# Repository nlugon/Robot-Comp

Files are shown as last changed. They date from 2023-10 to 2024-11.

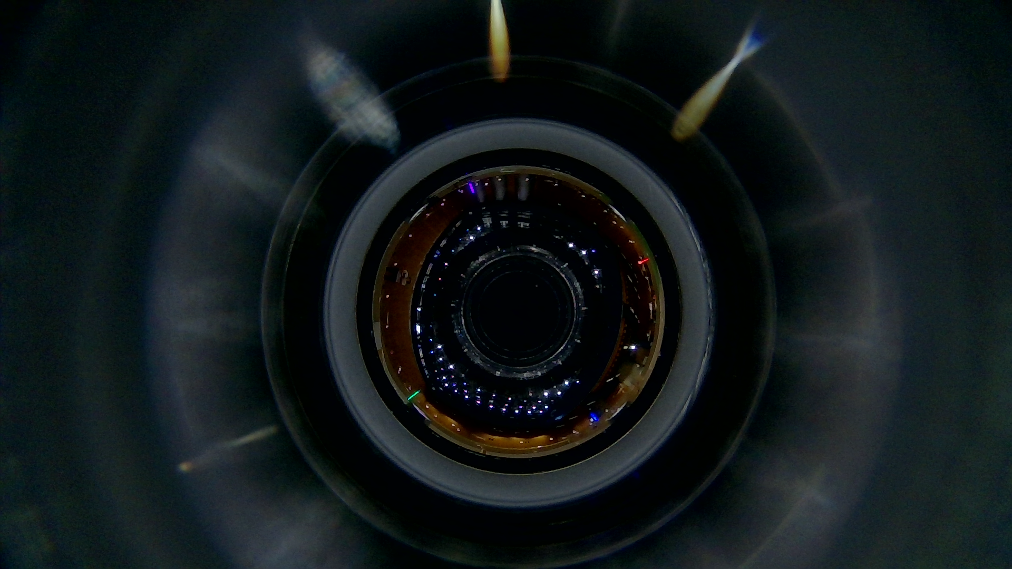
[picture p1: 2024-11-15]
Code/Utils/TestImages/image.png

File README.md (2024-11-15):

# Interdisciplinary Robot Competition

leroboteny

Competition website [here](https://robot-competition.epfl.ch) 

Video of the robot [here (youtube)](https://www.youtube.com/watch?v=vqCzc3zlJ8U)

Robot Competition Report [here](https://drive.google.com/file/d/1sISDkwHlUgYIt9PJVt_OxYXLAwWDXRC6/view)

## Authors
- [Noah Lugon](https://github.com/nlugon)
- [Clarence Linden](https://gitlab.epfl.ch/linden)
- [Adrien Chevallier](https://gitlab.epfl.ch/achevall)

## Electrical Components
- Arduino -> low level processing unit
- Raspberry Pi -> high level processing unit
- Maxon motors -> high precision motors for differential drive locomotion 
- Polulu motors -> motors for turning front brushes
- Servo motor -> for duplo brick unloading
- Servo driver -> Adafruit 16-Channel 12-bit PWM/Servo Driver (controlled by Arduino via I2C)
- Ultrasonic distance senors -> for distance measuring
- LEDs -> WS2812B Addressable RGB LED Strip with 32 LEDs used for esthetic as well as debugging purposes
    Center LEDs (14 to 17) used to indicate battery level
    Left and right LEDs (0-9 and 22-31) used to indicate if obstacle detected on left or right side (display in pink)
        Left and right LEDs also used to indicate other modes (turquoise for unloading, yellow for pressing button, 
            red for maneuver due to too high Maxon motor current, blue for maneuver if get stuck too long in a corner)

## Features
- Maxon motor speed control
- Maxon motor sensor data reading 
    Speed data for odometry -> if robot keeps detecting an obstacle in the same position, will make maneuver (turn randomly left or right by approx 180 deg)
    Current sensing -> if duplo ramp gets stuck under carpet, robot senses unusually high torque and makes backwards maneuver, followed by random left or right maneuver
- Polulu motor speed control (tuned constant speed here)
- Polulu motor encoder reading (if either of the two motors has low speed or gets stuck -> direction reversed for both motors to push duplo brick out)
- Servo control for unloading
- Simple and very robust obstacle avoidance by reversing direction of motor when an obstacle on the opposite side of the robot is detected
- Obstacle avoidance disabled during maneuvers, as well as when Arduino is commanded to run straight to the button (current sensing then used to determine when button is pressed)
  Extra feature of button pressing : when button pressed, robot always turns left (use_random_direction boolean set to false, set back to true once Raspberry Pi sends new motor command "m...") 

- Serial communication with Raspberry pi
Motor commands : "m+99-50" (first three characters after the 'm' is for the left motor, then the next three for the right)
    This custom protocal using a '+' or '-' character enables to choose between positive or negative motor speeds
Unloading command : "u"
Full arduino autonomous mode : "a" (basically resets default speed to +99 on left and right motors)
Move forward to push button : "b"
Emergency STOP command : "s"
Raspberry pi requests data : "d"
    Upon request, data formats received from arduino to raspberry pi :
        "dxxx xxx xxx xxx xxx xxx " with "xxx" representing distance measured by ultrasonic sensor in cm 
    As soon as low battery detected : "b" sent continuously, indicating low battery voltage -> robot should return to collecting point and stop brushes from turning to save battery      
Polulu motor command : "D1" to turn off, "D0" to turn on (default) (D for Debug)
    Note : if D0 sent but the polulus are not connected to the power source, there will be very high delayes due to the pulseIn() function awaiting motor encoder data (timeout set to 250ms)

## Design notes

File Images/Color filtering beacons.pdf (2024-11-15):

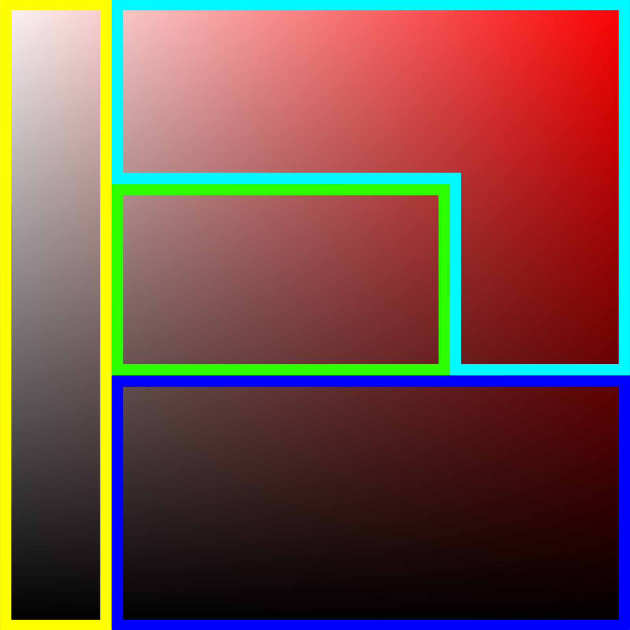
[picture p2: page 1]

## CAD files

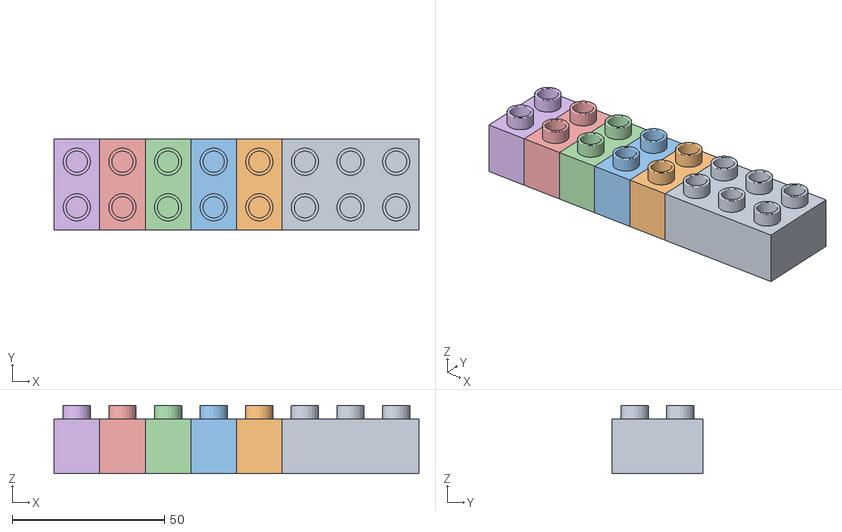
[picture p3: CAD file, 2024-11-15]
blender/Models Data/Duplo Parametrique 2x8.obj
120.0 x 30.0 x 22.5

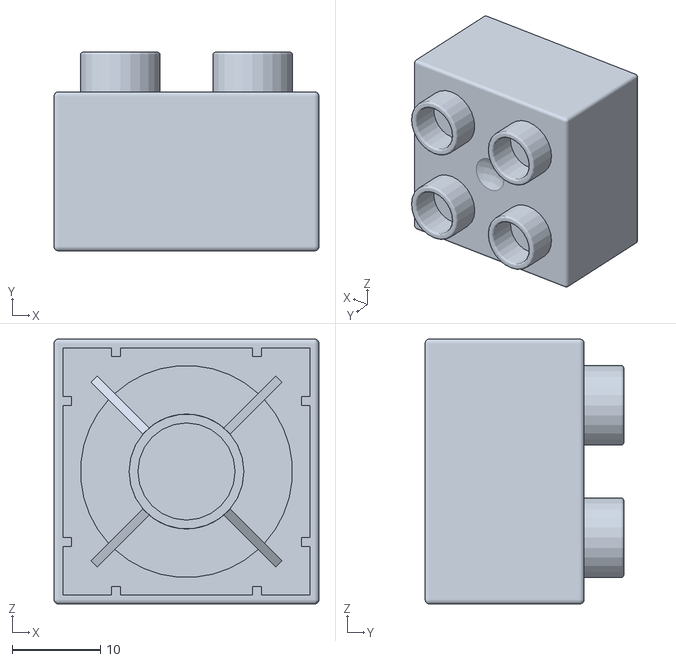
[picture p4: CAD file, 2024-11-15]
blender/Models Data/Duplo Parametrique 2x2.obj
30.0 x 22.5 x 30.0

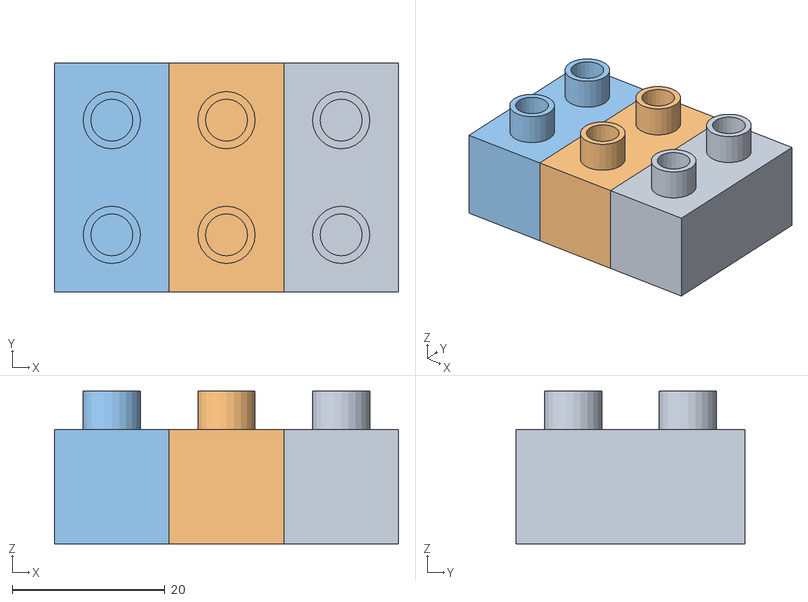
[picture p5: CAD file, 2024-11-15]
blender/Models Data/new/Duplo Parametrique 2x3.obj
45.0 x 30.0 x 20.0

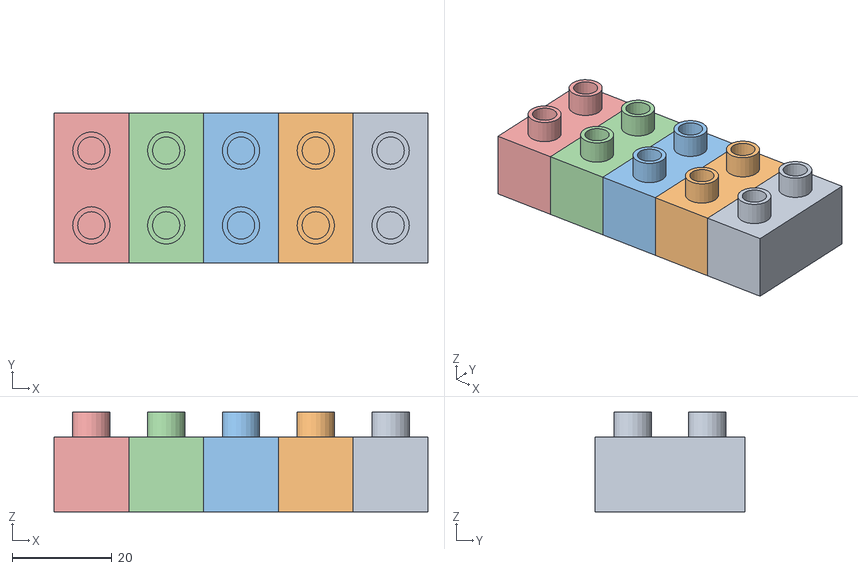
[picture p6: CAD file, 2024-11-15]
blender/Models Data/Duplo Parametrique 2x5.obj
75.0 x 30.0 x 20.0

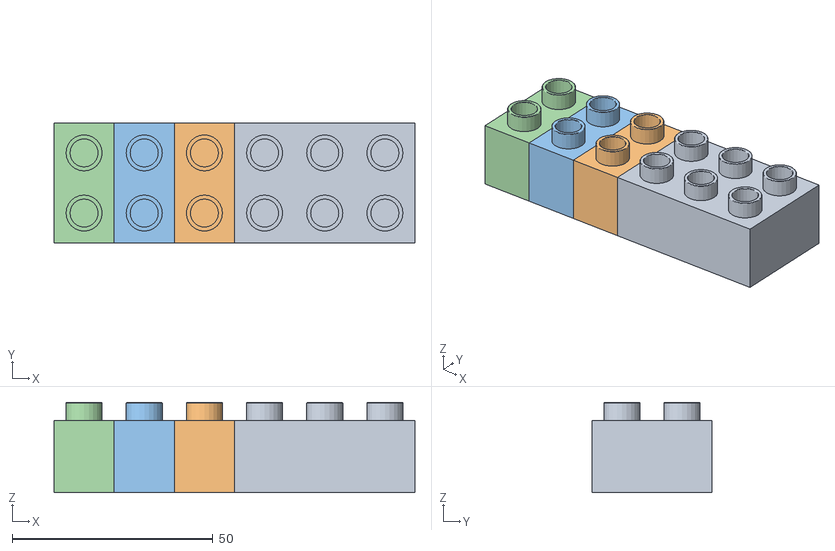
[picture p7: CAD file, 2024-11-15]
blender/Models Data/Duplo Parametrique 2x6.obj
90.0 x 30.0 x 22.5

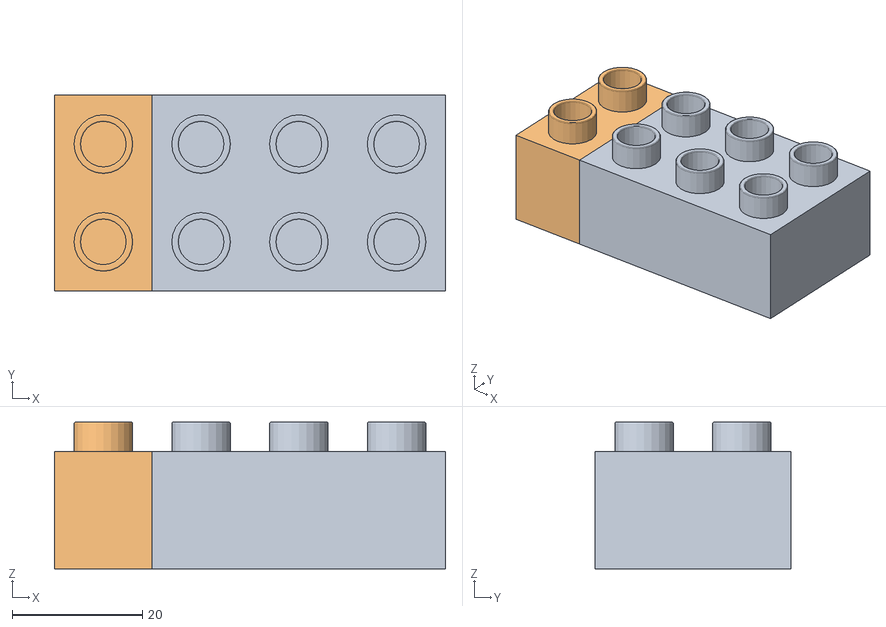
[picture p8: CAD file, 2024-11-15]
blender/Models Data/Duplo Parametrique 2x4.obj
60.0 x 30.0 x 22.5

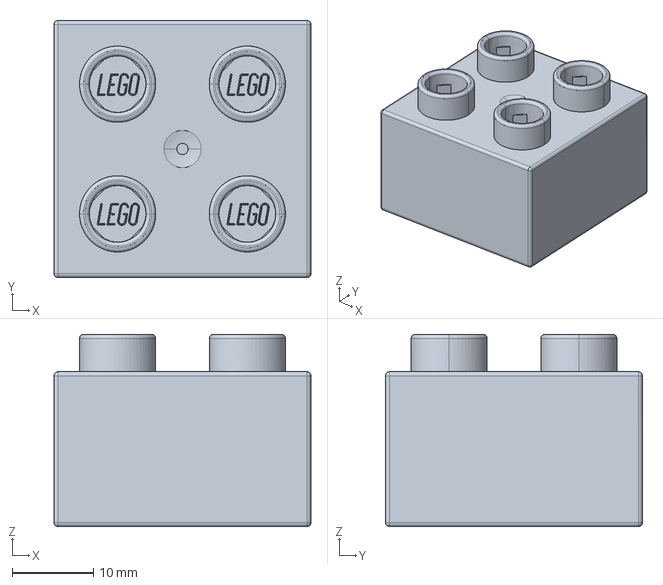
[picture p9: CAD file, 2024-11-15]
blender/Models Data/new/LEGO_DUPLO_BRICK_2X2.igs
31.7 x 31.7 x 23.7 mm

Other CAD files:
blender/Models Data/new/Duplo Parametrique 2x8.obj
blender/Models Data/new/Duplo Parametrique 2x5.obj
blender/Models Data/new/Duplo Parametrique 2x6.obj
blender/Models Data/Duplo Parametrique 2x3.obj
blender/Models Data/new/Duplo Parametrique 2x2.obj
blender/Models Data/new/Duplo Parametrique 2x4.obj
blender/Models Data/new/LEGO_DUPLO_BRICK_2X2 v1.stl

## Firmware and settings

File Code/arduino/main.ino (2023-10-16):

/* ARDUINO CODE 
  by Noah Lugon, last updated April 14 2023


  Main Components :
    - Arduino -> low level processing unit
    - Raspberry Pi -> high level processing unit
    - Maxon motors -> high precision motors for differential drive locomotion 
    - Polulu motors -> motors for turning front brushes
    - Servo motor -> for duplo brick unloading
    - Servo driver -> Adafruit 16-Channel 12-bit PWM/Servo Driver (controlled by Arduino via I2C)
    - Ultrasonic distance senors -> for distance measuring
    - LEDs -> WS2812B Addressable RGB LED Strip with 32 LEDs used for esthetic as well as debugging purposes
        Center LEDs (14 to 17) used to indicate battery level
        Left and right LEDs (0-9 and 22-31) used to indicate if obstacle detected on left or right side (display in pink)
            Left and right LEDs also used to indicate other modes (turquoise for unloading, yellow for pressing button, 
                red for maneuver due to too high Maxon motor current, blue for maneuver if get stuck too long in a corner)

  Features :
  - Maxon motor speed control
  - Maxon motor sensor data reading 
        Speed data for odometry -> if robot keeps detecting an obstacle in the same position, will make maneuver (turn randomly left or right by approx 180 deg)
        Current sensing -> if duplo ramp gets stuck under carpet, robot senses unusually high torque and makes backwards maneuver, followed by random left or right maneuver
  - Polulu motor speed control (tuned constant speed here)
  - Polulu motor encoder reading (if either of the two motors has low speed or gets stuck -> direction reversed for both motors to push duplo brick out)
  - Servo control for unloading
  - Simple and very robust obstacle avoidance by reversing direction of motor when an obstacle on the opposite side of the robot is detected
  - Obstacle avoidance disabled during maneuvers, as well as when Arduino is commanded to run straight to the button (current sensing then used to determine when button is pressed)
      Extra feature of button pressing : when button pressed, robot always turns left (use_random_direction boolean set to false, set back to true once Raspberry Pi sends new motor command "m...") 


  - Serial communication with Raspberry pi
    Motor commands : "m+99-50" (first three characters after the 'm' is for the left motor, then the next three for the right)
        This custom protocal using a '+' or '-' character enables to choose between positive or negative motor speeds
    Unloading command : "u"
    Full arduino autonomous mode : "a" (basically resets default speed to +99 on left and right motors)
    Move forward to push button : "b"
    Emergency STOP command : "s"
    Raspberry pi requests data : "d"
        Upon request, data formats received from arduino to raspberry pi :
            "dxxx xxx xxx xxx xxx xxx " with "xxx" representing distance measured by ultrasonic sensor in cm 
        As soon as low battery detected : "b" sent continuously, indicating low battery voltage -> robot should return to collecting point and stop brushes from turning to save battery      
    Polulu motor command : "D1" to turn off, "D0" to turn on (default) (D for Debug)
        Note : if D0 sent but the polulus are not connected to the power source, there will be very high delayes due to the pulseIn() function awaiting motor encoder data (timeout set to 250ms)


  WARNING ultrasonic sensor sometimes ouptut a value of 0 even when no obstacle is detected
    (solution : ignore 0 values, works very well in practice)

  WARNING When running the full code, the data sent from the Arduino to the Rasbperry Pi caused unexpected crashes of the main program on the Raspbery Pi.
      As we were unable to resolve this issue, no Serial data is sent to the Rasbperry Pi from the Arduino (no Serial.print())




  MAXON LEFT MOTOR CONNECTED TO MAXON CONTROLLER # 4
  Polulu left motor connected to M1 port of the motor driver

*/ 



#include <Servo.h>
#include <FastLED.h>

#include <Wire.h>
#include <Adafruit_PWMServoDriver.h>
Adafruit_PWMServoDriver pwm = Adafruit_PWMServoDriver();



#define SERVOMIN  200 // This is the 'minimum' pulse length count (out of 4096)
#define SERVOMAX  500 // This is the 'maximum' pulse length count (out of 4096)
#define SERVO_FREQ 60 // Analog servos run at ~50 Hz updates

#define LED_PIN     7
#define NUM_LEDS    32

#define ULTRASONIC_INTERVAL 40 // Milliseconds between sensor pings (29ms is about the min to avoid cross-sensor echo).
#define ULTRASONIC_NUM 5 // Number of sensors




bool DEBUG = 0;
bool use_random_direction = 1;
int randomNumber;
bool use_adafruit_driver = 1;


// FSM state
int fsmState = 0; // when state = 0, simple forward movement and obstacle avoidance
int turnTime = 1500;

// Polulu motor state and default speed
bool polulusOn = 1;
int poluluSpeed = 70; 

// variables used to detect changes of state between obstacle being detected / no longer being detected
bool obstacle = 0;
bool obstacleLeft = 0;
bool obstacleRight = 0;
bool prevObstacle = 0;
bool prevObstacleLeft = 0;
bool prevObstacleRight = 0;
bool NewObstacleState = 0; // if equals 1, indicates a change of state from (no obstacles detected) to (obstacle detected).




// LEDs
CRGB leds[NUM_LEDS];
// table of LED values, we found this is faster than using 
int ledStates[NUM_LEDS] = {0,0,0,0,0,0,0,0,0,0,0,0,0,0,0,0,0,0,0,0,0,0,0,0,0,0,0,0,0,0,0,0};
int prevLedStates[NUM_LEDS] = {0,0,0,0,0,0,0,0,0,0,0,0,0,0,0,0,0,0,0,0,0,0,0,0,0,0,0,0,0,0,0,0};


unsigned long currentTime = 0;

unsigned long ultrasonicTimer[ULTRASONIC_NUM]; // Holds the times when the next ping should happen for each sensor.
unsigned int cm[ULTRASONIC_NUM] = {100,100,100,100,100};         // Where the measured ultrasonic distances are stored.
bool obstacleState[ULTRASONIC_NUM] = {0,0,0,0,0};
//uint8_t currentUltrasonicSensor = 0;          // Keeps track of which sensor is active.
//unsigned int  ultrasonicSensors[ULTRASONIC_NUM];
// ULTRASONIC PINS
// const int ultrasonicTrigPins[ULTRASONIC_NUM] = {30,32,34,36,38,40};
// const int ultrasonicEchoPins[ULTRASONIC_NUM] = {31,33,35,37,39,41};
const int ultrasonicTrigPins[ULTRASONIC_NUM] = {42,32,34,36,38};
const int ultrasonicEchoPins[ULTRASONIC_NUM] = {43,33,35,37,39};



// SERVOMOTOR

// using adafruit driver
uint8_t servonum = 0;

// using arduino analogWrite pin
const int bigAssServoPin = 3;
int pos = 30;
Servo bigAssServo;





// MAXON CONTROLLER PINS
const int leftMotorEnablePin = 22;
const int leftMotorDirectionPin = 23;
const int leftMotorPwmPin = 10;

const int rightMotorEnablePin = 24;
const int rightMotorDirectionPin = 25;
const int rightMotorPwmPin = 11;

// DC MOTOR DRIVER PINS
const int MotorADirectionPin = 52;
const int MotorAPwmPin = 8;
const int MotorAEncoderPin = 50;

const int MotorBDirectionPin = 53;
const int MotorBPwmPin = 9;
const int MotorBEncoderPin = 51;


unsigned long startMillis;  // some global variables available anywhere in the program
unsigned long currentMillis;
const unsigned long poluluPeriod = 1000;  // after polulu motors detected to be stuck, turn brushes for 1s in outwards direction to spit out duplos 
const unsigned long poluluPeriodUnstuck = 200; // after polulu motos unstuck, give 200ms time for brushes to turn back inwards


unsigned long fsmStartMillis;
unsigned long fsmCurrentMillis;
const unsigned long fsmPeriod = 1000;

unsigned long obstacleCounter = 0;

unsigned long serialStartMillis;
unsigned long serialCurrentMillis;

unsigned long odometryStartMillis;
unsigned long odometryCurrentMillis;

// Maxon motor speed and drawn current data
int speedLeft = 0;
int currentLeft = 0;
int speedRight = 0;
int currentRight = 0;

// Odometry
long positionLeft;
long positionRight;
long positionForward;
long prevPositionForward;
long positionAngular;
bool not_moving_forward;

// Battery Monitoring
int batteryLevel = 0;

// Polulu motor encoder info
int ontimeA,offtimeA,dutyA;
float freqA, periodA;
int ontimeB,offtimeB,dutyB;
float freqB, periodB;
bool motorAstuck = 0;
bool motorBstuck = 0;

// Variables for ultrasonic sensors
long duration, distance, sonicSensor1;

// Communication with Raspberry Pi : 
String msg = "";

int left_speed = 99; // WARNING value between -99 and 99
int right_speed = 99; // WARNING value between -99 and 99



// FUNCTIONS
void SonarSensor();
void updateMotorCommands();
void getData();
void sendData();
void readSerialPort();
void sensorAvoidance();
void updatePoluluCommands();
void unloading();
void moveServos();
void adafruitCommand(int startPulse, int endPulse);
void analogWriteCommand(int startPos, int endPos);
void checkBatteryLevel();

void checkMotors();
void fsm();
void newFSMstate(int stateNumber = 0);

void updateLEDs();
void updateSideLEDs(int color);









/********************* SETUP *********************/

void setup() {
  // put your setup code here, to run once:
  Serial.begin(115200); // Initialize serial communication with computer

  // while (!Serial) {
  //   delay(10); // wait for serial port to connect. Needed for native USB port only
  // }


  // LEDs Initialization
  FastLED.addLeds<WS2812, LED_PIN, GRB>(leds, NUM_LEDS);
  // FastLED.setBrightness(10);
  for (uint8_t i = 0; i <= 31; i++) {
    leds[i] = CRGB (0, 0, 10); // blue
    FastLED.show();
    delay(40);
  }
  for (uint8_t i = 0; i <= 31; i++) {
    leds[i] = CRGB (0, 0, 0); // blue
    FastLED.show();
    delay(40);
  }

  checkBatteryLevel();
  updateLEDs();


  // SERVO CHECK : tilt duplo container up once upon startup
  if (use_adafruit_driver) {
      pwm.begin();
      pwm.setOscillatorFrequency(27000000);
      pwm.setPWMFreq(SERVO_FREQ);  // Analog servos run at ~50 Hz updates
      pwm.setPWM(servonum, 0, SERVOMIN);
      delay(1000);
      pwm.setPWM(servonum, 0, SERVOMAX);
      delay(1000);
      pwm.setPWM(servonum, 0, SERVOMIN);
      delay(1000);
      pwm.setPWM(0, 0, 0);  // turn off PWM signal to avoid servo humming
  }
  else {
    // SET PINS FOR SERVOMOTOR
    bigAssServo.attach(bigAssServoPin);
    bigAssServo.write(30);
    delay(1000);
    bigAssServo.write(130);
    delay(1000);
    bigAssServo.write(30);
    delay(1000);
  }


  // Odometry
  positionLeft = 0;
  positionRight = 0;
  positionForward = 0;
  prevPositionForward = positionForward;
  positionAngular = 0; 



  // SET PINMODE OF ULTRASONIC SENSORS
  for (uint8_t i = 0; i < ULTRASONIC_NUM; i++) { 
      pinMode(ultrasonicTrigPins[i], OUTPUT);
      pinMode(ultrasonicEchoPins[i], INPUT);
  }  

  // SET TIME WHEN EACH SENSOR SENDS PULSE (one after the other to avoid interference between sensors)
  ultrasonicTimer[0] = millis() + 1000; // First pulse starts at 1000ms
  for (uint8_t i = 1; i < ULTRASONIC_NUM; i++) { // Set the starting time for each sensor.
      ultrasonicTimer[i] = ultrasonicTimer[i - 1] + ULTRASONIC_INTERVAL;
  }

  
  // SET UP MAXON MOTOR CONTROLLER ********************
  pinMode(leftMotorEnablePin, OUTPUT);
  pinMode(leftMotorDirectionPin, OUTPUT);
  pinMode(leftMotorPwmPin, OUTPUT);
  pinMode(rightMotorEnablePin, OUTPUT);
  pinMode(rightMotorDirectionPin, OUTPUT);
  pinMode(rightMotorPwmPin, OUTPUT);

  digitalWrite(leftMotorEnablePin, HIGH); 
  digitalWrite(leftMotorDirectionPin, HIGH); 
  digitalWrite(rightMotorEnablePin, HIGH);
  digitalWrite(rightMotorDirectionPin, HIGH);

  analogWrite(leftMotorPwmPin,26); // pwm duty cycle set initially to 10% (corresponds to 0 speed)
  analogWrite(rightMotorPwmPin,26); // pwm duty cycle set initially to 10% (corresponds to 0 speed)

  // SET UP DC MOTOR DRIVER *********************
  pinMode(MotorADirectionPin, OUTPUT);
  pinMode(MotorAPwmPin, OUTPUT);
  pinMode(MotorAEncoderPin, INPUT);
  pinMode(MotorBDirectionPin, OUTPUT);
  pinMode(MotorBPwmPin, OUTPUT);
  pinMode(MotorBEncoderPin, INPUT);

  digitalWrite(MotorADirectionPin, LOW);
  digitalWrite(MotorBDirectionPin, HIGH);
  analogWrite(MotorAPwmPin, 80);
  analogWrite(MotorBPwmPin, 80);



  // Variables for time measurement purposes (to not slow down everything with delay() )
  startMillis = millis(); // for polulu motors
  currentMillis = startMillis;

  fsmStartMillis = millis(); // for FSM
  fsmCurrentMillis = millis();
 
  serialStartMillis = millis(); // for serial communication (if Raspberry Pi no longer communicating to Arduino -> arduino sets speeds back to default)
  serialCurrentMillis = serialStartMillis;

  odometryStartMillis = millis(); // for odometry (get position from motor speeds)
  odometryCurrentMillis = odometryStartMillis;

  turnTime = 1500;
  // Say hello for sake of politeness
  // Serial.println("Hello from Arduinoooo");
  delay(1000); // wait 1 second


}



/********************* LOOP *********************/ 

void loop() {


  getData(); // get data from ultrasonic sensors
  // sendData(); // send data from ultrasonic sensors


  polulusOn = 1;  // WARNING set polulus on by default for each loop
  // polulu may be turned off if : 
  // 1) ordered off by readSerialPort() ("D1" -> DEBUG = true)
  // 2) ordered off by checkMotors() (Maxon motors stalling -> avoid Lipo protection board disconnecting power) 
  // 3) ordered off by checkBatteryLevel() (measured battery level too low -> save energy and avoid Lipo protection board disconnecting power)
  

  readSerialPort(); // this function may set polulus to 0 

  checkMotors(); // this function may set polulus to 0 (used in updatePoluluCommands()) and change TurnTime (used in fsm();)
  
  checkBatteryLevel(); // this function may set polulus to 0

  updatePoluluCommands(); 

  fsm();

  updateLEDs();

}
 



/********************* FUNCTIONS *********************/


void getData() {
  // Get sensor data from ultrasonic distance sensors    
  for (uint8_t i = 0; i < ULTRASONIC_NUM; i++) { // Loop through all the sensors.
      if (millis() >= ultrasonicTimer[i]) {         // Is it this sensor's time to ping?
          SonarSensor(ultrasonicTrigPins[i], ultrasonicEchoPins[i]);
          cm[i] = distance;
          ultrasonicTimer[i] += ULTRASONIC_INTERVAL * ULTRASONIC_NUM;  // Set next time this sensor will be pinged.
      }      
  }
}

void fsm() {

  switch (fsmState) {
      case 0:
        // use_random_direction = 1;
        digitalWrite(leftMotorDirectionPin, HIGH);
        digitalWrite(rightMotorDirectionPin, HIGH);
        updateMotorCommands();
        sensorAvoidance();
        break;
      case 1: // LEFT TURN OF DURATION 
        fsmCurrentMillis = millis();
        digitalWrite(leftMotorDirectionPin, LOW);
        digitalWrite(rightMotorDirectionPin, HIGH);
        analogWrite(leftMotorPwmPin, map(99, 0, 99, 26, 230));
        analogWrite(rightMotorPwmPin, map(99, 0, 99, 26, 230));
        // time spent turning should be proportional to wheel speed
        if (fsmCurrentMillis - fsmStartMillis >= turnTime) {
          // fsmState = 0;
          newFSMstate(0);
        }
        break;

      case 2: // RIGHT TURN OF DURATION turnTime
        fsmCurrentMillis = millis();
        digitalWrite(leftMotorDirectionPin, HIGH);
        digitalWrite(rightMotorDirectionPin, LOW);
        analogWrite(leftMotorPwmPin, map(99, 0, 99, 26, 230));
        analogWrite(rightMotorPwmPin, map(99, 0, 99, 26, 230));

        // time spent turning should be proportional to wheel speed
        if (fsmCurrentMillis - fsmStartMillis >= turnTime) {
          // fsmState = 0;
          newFSMstate(0);
        }
        break;
  
      case 3: // BACKWARDS
        fsmCurrentMillis = millis();
        digitalWrite(leftMotorDirectionPin, LOW);
        digitalWrite(rightMotorDirectionPin, LOW);
        analogWrite(leftMotorPwmPin, map(99, 0, 99, 26, 230));
        analogWrite(rightMotorPwmPin, map(99, 0, 99, 26, 230));
        if (fsmCurrentMillis - fsmStartMillis >= 1500) {
          // fsmStartMillis = millis();
          // fsmState = 1;
          newFSMstate(1);
          if (use_random_direction) {
            randomNumber = (analogRead(A0)%2)+1; // random number between 1 and 2 for deciding whether to turn left or right
            // Serial.println(randomNumber);
            newFSMstate(randomNumber);
          }
        }
        break;
      case 4: // FORWARDS
        fsmCurrentMillis = millis();
        digitalWrite(leftMotorDirectionPin, HIGH);
        digitalWrite(rightMotorDirectionPin, HIGH);
        analogWrite(leftMotorPwmPin, map(99, 0, 99, 26, 230));
        analogWrite(rightMotorPwmPin, map(99, 0, 99, 26, 230));

        if (fsmCurrentMillis - fsmStartMillis >= 500) {
          newFSMstate(0); 
        }
        break;

      case 5: // FORWARD and press button
        use_random_direction = 0;
        fsmCurrentMillis = millis();
        digitalWrite(leftMotorDirectionPin, HIGH);
        digitalWrite(rightMotorDirectionPin, HIGH);
        analogWrite(leftMotorPwmPin, map(99, 0, 99, 26, 230));
        analogWrite(rightMotorPwmPin, map(99, 0, 99, 26, 230));

        if (fsmCurrentMillis - fsmStartMillis >= 10000) {
          newFSMstate(1); // always turn left after hitting button
          turnTime = 1500;
        }
        break;

      default:
        fsmState = 0;
        break;
    }

}

void updatePoluluCommands() {

  if (polulusOn == 1 && !DEBUG) {

      // COMMANDS TO DC MOTOR CONTROLLER
      analogWrite (MotorAPwmPin, poluluSpeed);      //PWM Speed Control   
      analogWrite (MotorBPwmPin, poluluSpeed); 

      // MEASURE POLULU MOTOR SPEED
      ontimeA = pulseIn(MotorAEncoderPin,HIGH, 250000); // timeout set to 250 ms 
      ontimeB = pulseIn(MotorBEncoderPin,HIGH, 250000);
      offtimeA = pulseIn(MotorAEncoderPin,LOW, 250000);
      offtimeB = pulseIn(MotorBEncoderPin,LOW, 250000);
      periodA = ontimeA+offtimeA;
      freqA =   1000000.0/periodA;
      periodB = ontimeB+offtimeB;
      freqB =   1000000.0/periodB;


      // Note : if value is inf (meaning period is 0), then motor is not turning (powered off or stuck)

      if (motorAstuck == 0){
        currentMillis = millis();  //get the current time 
        if (currentMillis - startMillis >= poluluPeriodUnstuck) {
          if (freqA < 200 || freqB < 200 || freqA > 5000 || freqB > 5000) {
            // Values manually tuned
            // under 200 means brushes are spinning too slow, very high value (set to 5000 instead of "inf") means brushes not moving 
            digitalWrite(MotorADirectionPin, HIGH);
            digitalWrite(MotorBDirectionPin, LOW);
            motorAstuck = 1;
            startMillis = millis();  //initial start time when motors considered stuck
          }          
        }
      }

      if (motorAstuck == 1){
        currentMillis = millis();  //get the current time 
        if (currentMillis - startMillis >= poluluPeriod) {
            digitalWrite(MotorADirectionPin, LOW);
            digitalWrite(MotorBDirectionPin, HIGH);
            motorAstuck = 0;
            // delay(100); // avoid delays using millis() below :
            startMillis = millis();  //initial start time when motors considered unstuck
        }
      }
  }

  else {
      analogWrite (MotorAPwmPin,0);      // if polulusOn == 0 or DEBUG == 1, Stop Polulu motors   
      analogWrite (MotorBPwmPin,0);
  }  
}

void SonarSensor(int trigPin,int echoPin) {

  digitalWrite(trigPin, LOW);
  delayMicroseconds(2);
  digitalWrite(trigPin, HIGH);
  delayMicroseconds(10);
  digitalWrite(trigPin, LOW);
  duration = pulseIn(echoPin, HIGH);
  distance = duration/58.2; // convert measurement data to cm
}
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

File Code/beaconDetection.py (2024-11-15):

import cv2 as cv
import numpy as np
import matplotlib.pyplot as plt
import time
import os
import random

from utils import *


# The goal is to detect the beacons, there are 4 beacons in each corners of the arena, 
# the camera is using a 360 degree kogeto lens, so the camera can see the whole arena
# the beacons are neons, there are pink, red, green and blue 
# on the kogeto lens, we see them as lines pointing to the center of the arena
# the goal is to get the angle of the line


def getAngleFrom3Points(A,B,C):
    """
    calcules the angle between 3 points, using the middle point as the reference (called B)

    --------------------------------------------------------------
    Input:
        A (float,float), [m]
        B (float,float), [m]
        C (float,float), [m]

    --------------------------------------------------------------
    Output: 
        angle (float), [rad]
    
    """
    
    # B is the middle point
    line1 = [A[0] - B[0], A[1] - B[1]]
    line2 = [C[0] - B[0], C[1] - B[1]]

    # calculate the angle with arctan
    angle = - np.arctan2(line1[1], -line1[0]) + np.arctan2(line2[1], -line2[0])
    # angle = np.arccos(np.dot(line1, line2) / (np.linalg.norm(line1) * np.linalg.norm(line2))) #2nd method, using alkashif formula

    return angle

def getLine(currentImg, middle):
    """
    detects the longest line pointing to the middle of the image

    --------------------------------------------------------------
    Input:
        currentImg (np.ndarray)
        middle (float,float), [m]

    --------------------------------------------------------------
    Output: 
        maxLine (float,float,float,float), [m]
        currentImg (np.ndarray)
    
    """

    # get the edges of the image
    edges = cv.Canny(currentImg, 50, 150, apertureSize=3)

    # use houghlines to detect the lines
    lines = cv.HoughLinesP(edges, 2, np.pi/360, 10, minLineLength=10, maxLineGap=10)

    maxLine = None

    # draw the lines on the image
    if lines is not None:
        # take the longest line
        maxLine = None
        for line in lines:
            for x1, y1, x2, y2 in line:

                

                angle = getAngleFrom3Points([x2,y2],[x1,y1],middle)
                angle = angle22pi(angle)

                threshold = np.pi / 4

                # only keep the line pointing to the middle(wihtin a 10 degree range)
                if abs(angle) < threshold or abs(angle - np.pi) < threshold or abs(angle - 2 * np.pi) < threshold: 
                    # cv.putText(currentImg, str(round(angle * rad2deg, 2)), (x1, y1), cv.FONT_HERSHEY_SIMPLEX, 1, (255, 255, 255), 2, cv.LINE_AA)
                    # cv.line(currentImg, (x1, y1), (x2, y2), (255, 0, 255), 2)

                    # if the line is longer than the maxLine, replace it
                    if maxLine is None:
                        maxLine = line
                    elif np.linalg.norm([x2-x1,y2-y1]) > np.linalg.norm([maxLine[0][2]-maxLine[0][0],maxLine[0][3]-maxLine[0][1]]):
                        maxLine = line
                else:
                    # cv.circle(currentImg, (x1, y1), 5, (0, 0, 255), 1)
                    # cv.line(currentImg, (x1, y1), (x2, y2), (0, 255, 255), 2)
                    # cv.putText(currentImg, str(round(angle * rad2deg, 2)), (x1, y1), cv.FONT_HERSHEY_SIMPLEX, 1, (255, 0, 0), 2, cv.LINE_AA)
                    pass
                
        # draw the longest line
        if maxLine is not None:
            for x1, y1, x2, y2 in maxLine:
                pass
                # cv.line(currentImg, (x1, y1), (x2, y2), (255, 0, 0), 2)
                # line1 = [x2 - x1, y2 - y1]
                # line2 = [middle[0] - x1, middle[1] - y1]

                # angle = np.arccos(np.dot(line1, line2) / (np.linalg.norm(line1) * np.linalg.norm(line2)))

                # cv.putText(currentImg, str(round(angle, 2)), (x1, y1), cv.FONT_HERSHEY_SIMPLEX, 1, (255, 255, 255), 2, cv.LINE_AA)

    return maxLine,currentImg


def getAngleFromLine(line,middle):
    """
    Get the angle to the middle from the line data

    --------------------------------------------------------------
    Input:
        line (float,float,float,float), [m]
        middle (float,float), [m]

    --------------------------------------------------------------
    Output: 
        angle (float), [rad]
    
    """

    X = Y = 0

    for x1, y1, x2, y2 in line:
        X = x1 if (abs(x1-middle[0]) > abs(x2-middle[0])) else x2
        Y = y1 if (abs(y1-middle[1]) > abs(y2-middle[1])) else y2

    # calculate the angle with the middle

    angle = getAngleFrom3Points([X,Y],middle,[0,middle[1]])

    return angle

def getRange(Channel, lower, upper, maxVal = 180,mask = None):
    """
    Make the mask for the hue layer, with the given range, range can be from 0 to 360
    Range can be overlapping (lower > upper) like for red (0-30 and 330-360)

    --------------------------------------------------------------
    Input:
        Channel (np.ndarray)
        lower (int), [0-360]
        upper (int), [0-360]
        maxVal (int), [0-360]

    --------------------------------------------------------------
    Output: 
        variable (type) [unit]
    
    """

    if mask is None:
        mask = np.ones(Channel.shape, dtype=np.uint8)*255

    if lower < upper:
        return cv.bitwise_and(cv.inRange(Channel, lower, upper),mask)
    else:
        return cv.bitwise_and(cv.bitwise_or(cv.inRange(Channel, lower, maxVal),cv.inRange(Channel, 0, upper)),mask)
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
